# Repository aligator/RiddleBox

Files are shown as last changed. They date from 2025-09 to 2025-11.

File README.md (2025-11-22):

[Online 3d model - click here](https://ochafik.com/openscad2/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)

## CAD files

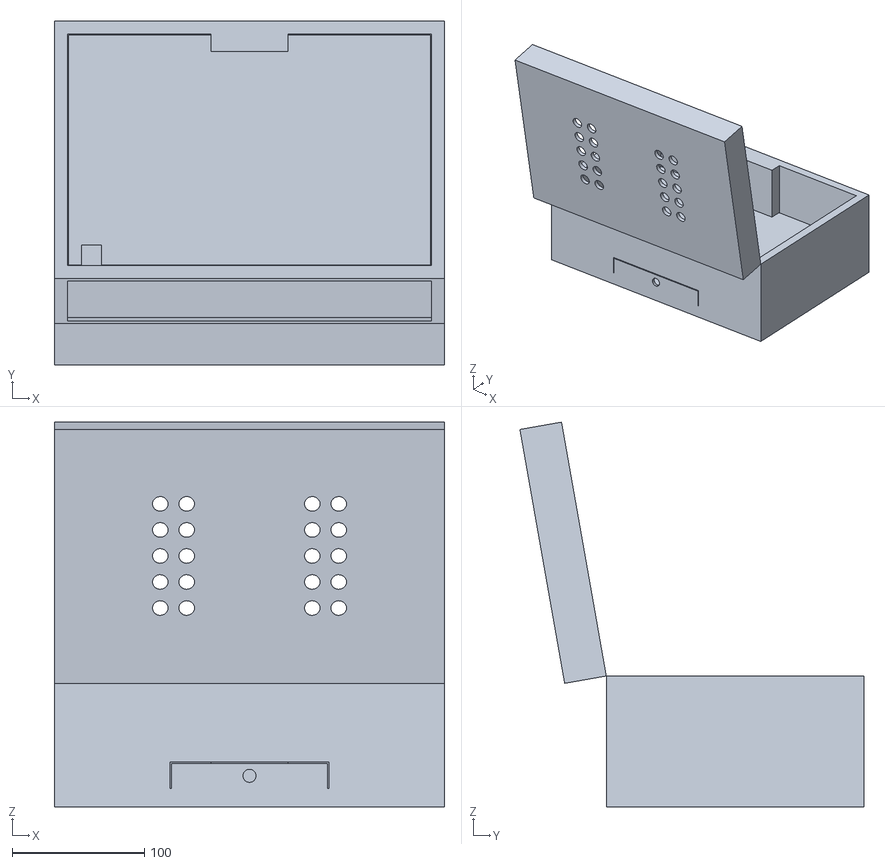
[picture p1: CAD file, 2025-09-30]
RiddleBox.stl
295.0 x 260.4 x 291.0

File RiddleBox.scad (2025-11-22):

// Wooden box with false bottom, secret drawer and RCA cutouts in lid

// ---------- Feature toggles ----------
show_box_body     = true;
show_lid          = true;
show_false_bottom = true;
show_drawer       = true;
show_drawer_cut   = true;
show_rca_cutouts  = true;
show_lock         = true;

show_only_false_bottom_lasercut = false;

// ---------- Parameters ----------
// Master dimensions
// outer length (X, mm)
outer_len = 300;
// outer width (Y, mm)
outer_w   = 200;
// outer height (Z, mm)
outer_h   = 140;

// inner height (Z, mm)
inner_h   = 85;

// Wall thickness
// left/right walls (X)
wall_x = 12.5;
// front/back walls (Y)
wall_y = 12.5;

// Base and lid
// lid block thickness
lid_th  = 32;  // bottom thickness
base_th = outer_h-inner_h-lid_th;

// size of the false-bottom supports
false_bottom_support_width = 10;


// Hidden compartment
// hidden drawer height (Z)
hidden_h        = 20;
// false bottom thickness
false_bottom_th = 5;
// drawer length in X direction (< inner_len)
drawer_len      = 120;
// space between the drawer and the front wall. (For example to make space for the lock electronic if the lock goes into the false-bottom)
drawer_y_space  = 14;
// clearance for drawer (mm)
drawer_clear    = 1.0;
// wall thickness of drawer
drawer_wall     = 3;
// hole for the power cable
drawer_power_hole_d = 10;
// hole offset to the left (so that the cable does not collide with the internal electronic
drawer_power_hole_offset_to_left = 0;
drawer_power_hole_offset_to_top = 0;

// Cable
// Cable coutouts in the false bottom and the drawer
cable_cutout = 15;

// Derived dimensions
inner_len = outer_len - 2*wall_x;
inner_w   = outer_w   - 2*wall_y;
visible_inner_h   = outer_h - base_th - lid_th - hidden_h - false_bottom_th;

// hollow inside lid
lid_cutout = 24;

// RCA cutouts (lid)
// hole diameter for RCA jacks
rca_hole_d = 8;
// number of columns per block
rca_cols   = 2;
// number of rows per block
rca_rows   = 5;
// spacing between columns
rca_pitch_x = 20;
// spacing between rows
rca_pitch_y = 20;
// margin from left/right side
rca_margin_side  = 80;

// Display
// degrees, 0 = closed, 100 = open
lid_open_angle = 100; 

// Electronic Lock height (only the base shape for vizualization)
lock_ht=73;
lock_width=13.1;
lock_len=58;
lock_shift_up=0;

lock_false_bottom_cutout_margin=1;

c0=0.01+0;

// ---------- Dimension printout ----------
echo("Inner length (X) =", inner_len, "mm");
echo("Inner width (Y)  =", inner_w, "mm");
echo("Visible inner height (Z) =", visible_inner_h, "mm");
echo("Hidden drawer height (Z) =", hidden_h, "mm");
echo("False bottom thickness (Z) =", false_bottom_th, "mm");
echo("Total internal height (Z) =", visible_inner_h + hidden_h + false_bottom_th, "mm");

echo("lock space left", visible_inner_h - lock_ht+lock_shift_up);

// ---------- Modules ----------
module box_body(){
    difference(){
        // Outer shell without lid
        cube([outer_len, outer_w, outer_h - lid_th], center=false);

        // Hollow interior from base up to lid
        translate([wall_x, wall_y, base_th])
            cube([inner_len, inner_w, outer_h - lid_th - base_th + c0], center=false);

        // Rear cutout for drawer access
        if (show_drawer_cut)
            translate([wall_x + inner_len/2 - drawer_len/2, -c0, base_th])
                cube([drawer_len, wall_y+2+c0, hidden_h], center=false);
    }
    
    translate([wall_x, wall_y, base_th])
        cube([false_bottom_support_width, inner_w, hidden_h]);
    translate([inner_len, wall_y, base_th])
        cube([false_bottom_support_width, inner_w, hidden_h]);

}

module lock(margin=0) {
    translate([outer_len/2-lock_len/2-margin,
               wall_y+inner_w-lock_width-margin,
               base_th + hidden_h + false_bottom_th+visible_inner_h - lock_ht + lock_shift_up])
        cube([lock_len+margin*2, lock_width+margin*2, lock_ht], center=false);
}

module lid_block(){
    difference(){
        cube([outer_len, outer_w, lid_th], center=false);

        // Hollow inside lid
        translate([wall_x, wall_y, -c0])
            cube([inner_len, inner_w, lid_cutout+c0], center=false);

        // RCA cutouts in lid
        if (show_rca_cutouts)
            translate([0, 0, -lid_th])
            rca_cutouts();
    }
}

module drawer(){
    difference(){
        // Outer size = hidden space minus clearance
        cube([drawer_len-2*drawer_clear,
              inner_w + wall_y - drawer_y_space,
              hidden_h-drawer_clear], center=false);

        // Inner hollow, top open
        translate([drawer_wall, drawer_wall, drawer_wall])
            cube([drawer_len-2*drawer_clear-2*drawer_wall,
                  inner_w+wall_y - drawer_wall*2 - drawer_y_space,
                  hidden_h-drawer_clear], center=false);

        // Power cable hole in front
        translate([(drawer_len-2*drawer_clear)/2-drawer_power_hole_offset_to_left,
                   drawer_wall+c0,
                   (hidden_h-drawer_clear)/2+drawer_power_hole_offset_to_top])
            rotate([90, 0, 0])
            cylinder(d=drawer_power_hole_d, h=drawer_wall+2*c0);
        
        // Cable
        translate([-c0, drawer_wall-cable_cutout+inner_w+wall_y - drawer_wall*2 - drawer_y_space, drawer_wall])
        cube([drawer_wall+2*c0, cable_cutout, hidden_h+c0]);
    }
}

module false_bottom(){
    // Plate above the hidden drawer with clearance
    difference() {
        translate([wall_x+0.5, wall_y+0.5, base_th + hidden_h]) {
            difference() {
                cube([inner_len-1, inner_w-1, false_bottom_th], center=false);
                translate([false_bottom_support_width, 0, -c0])
                    cube([cable_cutout, cable_cutout, false_bottom_th+2*c0]);
            }
        }
        
        lock(lock_false_bottom_cutout_margin);
    }
}


module false_bottom(){
    // Plate above the hidden drawer with clearance
    difference() {
        translate([wall_x+0.5, wall_y+0.5, base_th + hidden_h]) {
            difference() {
                cube([inner_len-1, inner_w-1, false_bottom_th], center=false);
                translate([false_bottom_support_width, 0, -c0])
                    cube([cable_cutout, cable_cutout, false_bottom_th+2*c0]);
            }
        }
        
        lock(lock_false_bottom_cutout_margin);
    }
}

module false_bottom_lasercut() {
    projection(cut = false) false_bottom();
}

// RCA cutout blocks (centered along Y axis of lid)
module rca_block(x_offset){
    total_height = (rca_rows-1)*rca_pitch_y;
    y_start = outer_w/2 - total_height/2;
    for (row=[0:rca_rows-1]){
        for (col=[0:rca_cols-1]){
            translate([x_offset + col*rca_pitch_x,
                       y_start + row*rca_pitch_y,
                       lid_th - c0])
                cylinder(d=rca_hole_d, h=lid_th+2*c0, center=false);
        }
    }
}

module rca_cutouts(){
    // Left block
    rca_block(rca_margin_side);
    // Right block
    rca_block(outer_len - rca_margin_side - (rca_cols-1)*rca_pitch_x);
}

// ---------- Assembly ----------
module assembly(){
    if (show_box_body)
        color("burlywood") box_body();

    if (show_lid)
        translate([0,0,outer_h - lid_th])
            rotate([lid_open_angle,0,0])
                color("sienna") lid_block();

    if (show_false_bottom)
        color("saddlebrown") false_bottom();

    if (show_drawer)
        translate([wall_x + inner_len/2 - drawer_len/2 + drawer_clear,
                   0,
                   base_th])
            color("peru") drawer();

    // Lock vorne
    if (show_lock)
        color("gray") lock();
}

// ---------- Main ----------
if (!show_only_false_bottom_lasercut)
    assembly();
else
    false_bottom_lasercut();

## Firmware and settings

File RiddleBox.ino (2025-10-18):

#include <Wire.h>

// MXP23017 lib: https://github.com/blemasle/arduino-mcp23017
#include <MCP23017.h>

// MCP23017 IO Expander i2c pins
constexpr int PIN_SDA    = 21;   // ESP32 SDA
constexpr int PIN_SCL    = 22;   // ESP32 SCL
constexpr uint8_t I2C_ADDRESS = 0x20; // I2C Adress of the chip
constexpr uint8_t I2C_ADDRESS_2 = I2C_ADDRESS + 1; // I2C Adress of the 2nd chip

// Configuration i/o
constexpr int PIN_LED    = 27;   // Status LED
constexpr int PIN_BUTTON = 18;   // Button input

// Action output
constexpr int PIN_RELAY  = 25;   // Relay output

// If not 0 the relay will be pulsed for the given ms. This is usefull for locks that need a short pulse only.
constexpr int RELAY_PULSE = 200; //0; 

constexpr int EMERGENCY_UNLOCK_MS = 3000;

MCP23017 mcp_1(I2C_ADDRESS);
MCP23017 mcp_2(I2C_ADDRESS_2);

// MCP Output pin configuration
constexpr uint8_t O_A1 = 0;
constexpr uint8_t O_B1 = 1;
constexpr uint8_t O_A2 = 2;
constexpr uint8_t O_B2 = 3;
constexpr uint8_t O_A3 = 4;
constexpr uint8_t O_B3 = 5;
constexpr uint8_t O_A4 = 6;
constexpr uint8_t O_B4 = 7;
constexpr uint8_t O_A5 = 8;
constexpr uint8_t O_B5 = 9;

const uint8_t outputPins[] = {
  0,  // O_A1
  1,  // O_B1
  2,  // O_A2
  3,  // O_B2
  4,  // O_A3  
  5,  // O_B3
  6,  // O_A4
  7,  // O_B4
  16, // O_A5 // 2nd io expander
  17  // O_B5 // 2nd io expander
};
const int numOutputs = sizeof(outputPins) / sizeof(outputPins[0]);

// MCP Input pin configuration
constexpr uint8_t I_C1 = 0;
constexpr uint8_t I_D1 = 1;
constexpr uint8_t I_C2 = 2;
constexpr uint8_t I_D2 = 3;
constexpr uint8_t I_C3 = 4;
constexpr uint8_t I_D3 = 5;
constexpr uint8_t I_C4 = 6;
constexpr uint8_t I_D4 = 7;
constexpr uint8_t I_C5 = 8;
constexpr uint8_t I_D5 = 9;

const uint8_t inputPins[]  = {
  9, // I_C1 // 2nd io expander
  25, // I_D1 // 2nd io expander
  8,  // I_C2  
  24,  // I_D2
  10, // I_C3
  11, // I_D3
  12, // I_C4
  13, // I_D4   
  14, // I_C5
  15  // I_D5
};
const int numInputs = sizeof(inputPins) / sizeof(inputPins[0]);


// Configure the possible lock-combinations.
// The first value must be an Output (O_)
// The second value must be an Input (I_)
const uint8_t config0[][2] = { 
  {O_A1, I_D5},
  {O_B2, I_D1},
  {O_A3, I_C2},
  {O_B4, I_D3},
  {O_A5, I_C3}
};
const uint8_t config1[][2] = { 
  {O_B1, I_D2},
  {O_A1, I_C4},
  {O_B2, I_D1},
  {O_A2, I_D5},
  {O_B3, I_C1},
  {O_A3, I_C3},
  {O_B4, I_C2},
  {O_A4, I_D3},
  {O_B5, I_D4},
  {O_A5, I_C5}
};

// All available configs must be registered here.
const uint8_t* configs[] = {
  (const uint8_t*)config0,
  (const uint8_t*)config1,
};
// And here.
const int configLengths[] = {
  sizeof(config0)/sizeof(config0[0]),
  sizeof(config1)/sizeof(config1[0]),
};

const int numConfigs = sizeof(configs)/sizeof(configs[0]);

// ---- State ----
int currentConfig = 0;
unsigned long lastButtonMsStart = 0;

bool relayOpen = false;

/**
 * Maps the pin to the mcp chip to be used.
 */
MCP23017 mapPinToMcp(uint8_t pin) {
  if (pin <= 15) {
    return mcp_1;
  } else {
    return mcp_2;
  }
}

/**
 * Maps the pin to the mcp chip pin (simple modulo)
 */
uint8_t mapMcpPin(uint8_t pin) {
  return pin % 16;
}

void setup() {
  Serial.begin(115200);
  Wire.begin(PIN_SDA, PIN_SCL);
  mcp_1.init();
  mcp_2.init();

  // Initialize outputs
  // Initialize them as inputs to prevent shortcuts done by connecting two outputs.
  // Only one output at a time is switched to output mode at a time when needed!
  for (int i = 0; i < numOutputs; i++) {
    MCP23017 mcp = mapPinToMcp(outputPins[i]);
    mcp.pinMode(mapMcpPin(outputPins[i]), INPUT);
  }
  // Initialize inputs (plain INPUT, external pull-downs required)
  for (int i = 0; i < numInputs; i++) {
    MCP23017 mcp = mapPinToMcp(inputPins[i]);
    mcp_1.pinMode(mapMcpPin(inputPins[i]), INPUT);
  }

  // Setup the other things.
  pinMode(PIN_LED, OUTPUT);
  pinMode(PIN_RELAY, OUTPUT);
  // Uses pullup -> button must pull-down to ground! (e.g. connect the input to ground)
  pinMode(PIN_BUTTON, INPUT_PULLUP); 

  Serial.println("RiddleBox is ready.");
}

void unlock(bool unlocked) {
  if (RELAY_PULSE == 0) {
    // Drive directly, as long as the lock is unlocked.
    digitalWrite(PIN_RELAY, unlocked ? HIGH : LOW);
  } else {
    if (!relayOpen && unlocked) {
      relayOpen = true;
      digitalWrite(PIN_RELAY, HIGH);
      delay(RELAY_PULSE);
      digitalWrite(PIN_RELAY, LOW);
    } else if (!unlocked) {
      relayOpen = false;
    }
  }
}

void loop() {
  unsigned long buttonPressedTime = millis() - lastButtonMsStart;
  if (lastButtonMsStart != 0 && buttonPressedTime > EMERGENCY_UNLOCK_MS) {
    // Signal that you have waited log enough to open the lock with emergency unlock
    digitalWrite(PIN_LED, HIGH);
  }

  // First check if the config switcher button was pressed (pressed==LOW). (debounced)
  if (digitalRead(PIN_BUTTON) == LOW) {
    if (lastButtonMsStart == 0) {
      lastButtonMsStart = millis();
    }
  } else {
    if (lastButtonMsStart != 0) {
      Serial.print("button pressed");
      Serial.println(buttonPressedTime);
      if (buttonPressedTime > EMERGENCY_UNLOCK_MS) {
        digitalWrite(PIN_LED, LOW);

        // Emergency unlock - press the button for more than EMERGENCY_UNLOCK_MS
        relayOpen = false;
        unlock(true);
      } else if (buttonPressedTime > 250) {
        // Switch config if the button was pressed less than EMERGENCY_UNLOCK_MS.
        currentConfig = (currentConfig + 1) % numConfigs;
        Serial.print("Switched to config ");
        Serial.println(currentConfig);
        showConfigNumber(currentConfig + 1);
      }
    }

    lastButtonMsStart = 0;
  }  

  // Then check all connections to find out if the lock is unlocked.
  bool unlocked = checkExactConfig(currentConfig);
  if (unlocked && !relayOpen && RELAY_PULSE != 0) {
    // Wait a bit before unlocking.
    delay(1000);
  }
  unlock(unlocked);

  // For debugging
  //delay(1000);
}

// Test exactly one output-input pair
bool pairConnected(uint8_t outPin, uint8_t inPin) {
  // Drive selected output HIGH
  MCP23017 mcp = mapPinToMcp(outPin);
  uint8_t pin = mapMcpPin(outPin);
  mcp.pinMode(pin, OUTPUT);
  mcp.digitalWrite(pin, HIGH);
  delayMicroseconds(300);

  // Read input
  MCP23017 mcp_read = mapPinToMcp(outPin);
  int val = mcp_read.digitalRead(mapMcpPin(inPin));

  // Reset output back to high-Z
  mcp.digitalWrite(pin, LOW);
  mcp.pinMode(pin, INPUT);

  return (val == HIGH);
}

// Check for exact config: required pairs only, no extras
bool checkExactConfig(int cfgIndex) {
  const uint8_t* cfg = configs[cfgIndex];
  int len = configLengths[cfgIndex];

  Serial.println("🔍 Live connections:");

  // These loops could be much more efficient,
  // however for this small project its just good enough^^ 
  // That is not my masterpiece software but it just works :-)

  // Collect all active pairs
  bool activePairs[numOutputs][numInputs] = {false};
  for (int o = 0; o < numOutputs; ++o) {
    // Drive selected output HIGH
    MCP23017 mcp = mapPinToMcp(outputPins[o]);
    uint8_t pin = mapMcpPin(outputPins[o]);
    mcp.pinMode(pin, OUTPUT);
    mcp.digitalWrite(pin, HIGH);
    delayMicroseconds(300);

    for (int i = 0; i < numInputs; ++i) {
      // Read input
      MCP23017 mcp_input = mapPinToMcp(inputPins[i]);
      int val = mcp_input.digitalRead(mapMcpPin(inputPins[i]));
      if (val == HIGH) {
        activePairs[o][i] = true;
        Serial.print("* O");
        Serial.print(outputPins[o]);
        Serial.print(" -> I");
        Serial.println(inputPins[i]);
      } else {
        activePairs[o][i] = false;
      }
    }

    // Reset output back to high-Z (short cut protection)
    mcp.digitalWrite(pin, LOW);
    mcp.pinMode(pin, INPUT);
    delayMicroseconds(300);
  }

  Serial.println("Check connections:");

  // Check if all required pairs are present
  for (int c = 0; c < len; ++c) {
    uint8_t outIndex = *(cfg + c*2 + 0);
    uint8_t inIndex = *(cfg + c*2 + 1);
    
    uint8_t outPin = outputPins[outIndex];
    uint8_t inPin  = inputPins[inIndex];

    if (!activePairs[outIndex][inIndex]) {
      Serial.println("✘ Required pair missing!");
      Serial.print("  O");
      Serial.print(outPin);
      Serial.print(" -> I");
      Serial.println(inPin);
      return false;
    }
  }

  // Check if there are extra pairs
  for (int o = 0; o < numOutputs; ++o) {
    for (int i = 0; i < numInputs; ++i) {
      if (activePairs[o][i]) {
        bool required = false;
        for (int c = 0; c < len; ++c) {
          uint8_t outIndex = *(cfg + c*2 + 0);
          uint8_t inIndex = *(cfg + c*2 + 1);
          
          uint8_t outPin = outputPins[outIndex];
          uint8_t inPin  = inputPins[inIndex];
          if (outputPins[o] == outPin && inputPins[i] == inPin) {
            required = true;
            break;
          }
        }
        if (!required) {
          Serial.print("✘ Extra connection detected: O");
          Serial.print(outputPins[o]);
          Serial.print(" -> I");
          Serial.println(inputPins[i]);
          return false;
        }
      }
    }
  }

  Serial.println("✔ Exact config, relay ON");
  return true;
}

// Blink LED with the number of current config
void showConfigNumber(int number) {
  for (int i = 0; i < number; i++) {
    digitalWrite(PIN_LED, HIGH);
    delay(180);
    digitalWrite(PIN_LED, LOW);
    delay(180);
  }
}

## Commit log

2025-09-28 Add Chinch holes
    [RiddleBox.scad]
2025-09-28 Add cutouts
    [RiddleBox.scad]
2025-09-28 Add electronic lock
    [RiddleBox.scad]
2025-09-28 Improve comments for the customizer
    [RiddleBox.scad]
2025-09-28 Add POC code for an esp32 dev board
2025-09-28 Fix performance by avoiding unnecessary calls to i2c
    [RiddleBox.ino]
2025-09-30 Some model improvements and configuration for my real box
    [RiddleBox.scad]
2025-09-30 Improve values
    [RiddleBox.scad]
2025-09-30 Fix wrong rca hole size
    [RiddleBox.scad]
2025-09-30 Update online viewer link
    [RiddleBox.stl]
2025-10-05 Improve pin mapping code and update pins to current actual used pins
2025-10-11 Update my real parameter set and add projection of the false bottom for a laser cut.
    [RiddleBox.scad]
2025-10-12 Add functionality to unlock when pressing the button for more than 3 seconds for "emergency" unlock
2025-10-12 Change pin order as I accidentally switched them physically
